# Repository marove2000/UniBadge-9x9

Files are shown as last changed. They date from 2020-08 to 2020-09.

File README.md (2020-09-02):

# UniBadge 9x9
A simple badge PCP with 9x9 LEDs. Create symbols, figures, pixel art by just soldering LEDs to the spots you want. No programming needed.

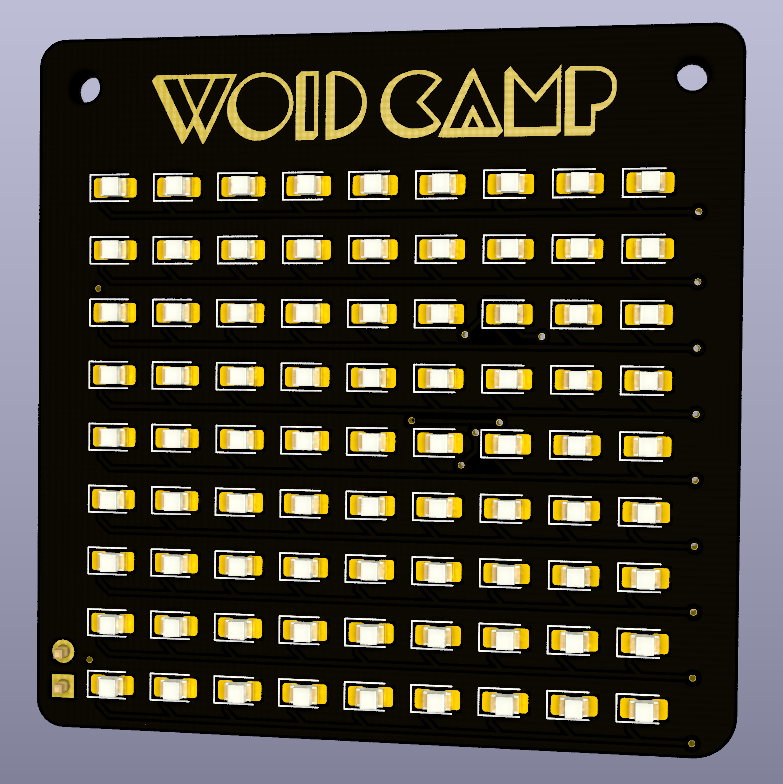
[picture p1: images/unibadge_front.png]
UniBadge 9x9 front
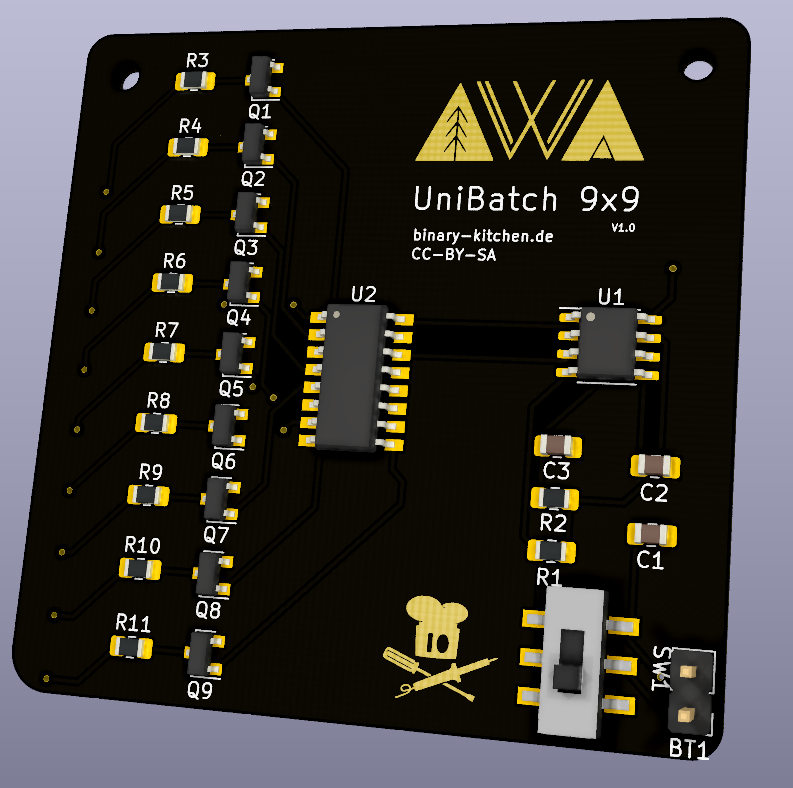
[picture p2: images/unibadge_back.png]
UniBadge 9x9 front
 

## Bill of Material
| Designator | Package | Quantity | Designation |
| --- | --- | --- | --- |
| BT1 | 2-Pin connector | 1 | Battery-Holder (2xAAA) |
| C1, C2 | 100nF | 2 | |
| C3 | 0805 SMD capacitor | 1 | variable (see capaictor table) |
| D1-D81 | 0805 SMD LED | 1-81 | LED red, green, orange, ... |
| Q1-Q9 | Mosfet | 9 | 2N7002 |
| R1, R2 | 0805 SMD resistor  | 2 | 100k |
| R3-R11 | 0805 SMD resistor  | 9 | variable (see resistor table)  |
| SW1 | SMD switch | 1 | |
| U1 | SOIC-8 NE555 | 1 | |
| U2 | SOP-16 CD4017 | 1 | |

### Capacitor-Table for C3
The frequency is determined by the value of C3. Always on: The frequency is so fast, it looks like all (soldered) LEDs are always on.

| Frequency | Capacitor Value (C3) |
| --- | --- |
| slow (~5Hz) | 1µF |
| faster (~50Hz) | 10nF |
| always on (~110Hz) | 4700pF / 4,7nF |

### Resistor-Table for R3-R11
Resistor values depend on the number of soldered LEDs per row (refer to the table below). Note that you can only choose one LED color per row.

| Number of LEDs | Resistor value for red LEDs | Resistor value for green LEDs (bright!) |
| --- | --- | --- |
| 1 | 56 Ohm | 110 Ohm |
| 2 | 27 Ohm | 56 Ohm |
| 3 | 18 Ohm | 36 Ohm |
| 4 | 15 Ohm | 30 Ohm |
| 5 | 11 Ohm | 22 Ohm |
| 6 | 9,1 Ohm | 18 Ohm |
| 7 | 8,2 Ohm | 16 Ohm |
| 8 | 6,8 Ohm | 13 Ohm |
| 9 | 6,2 Ohm | 12 Ohm |

## Manual
TBD

## Some creations
Some $humans did an amazing job. Here are some awesome examples:
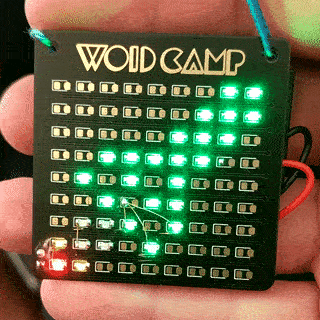
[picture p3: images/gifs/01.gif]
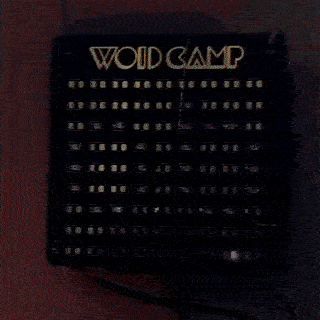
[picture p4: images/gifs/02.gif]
 
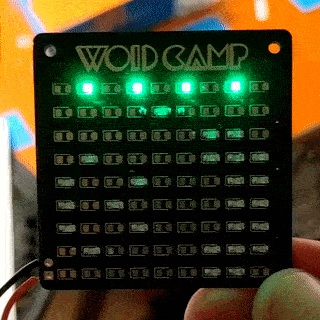
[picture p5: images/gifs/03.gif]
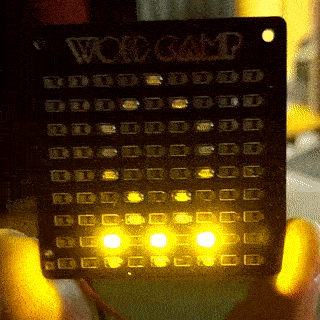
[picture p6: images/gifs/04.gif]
 
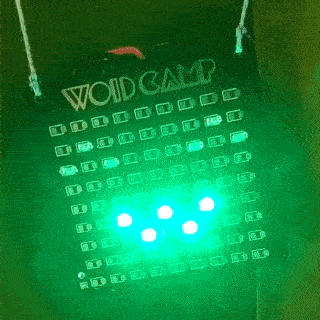
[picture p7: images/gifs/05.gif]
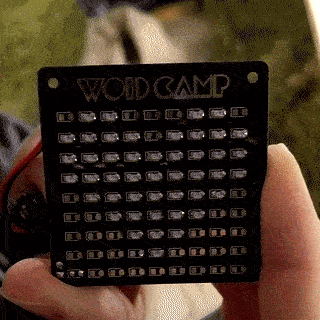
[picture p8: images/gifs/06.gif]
 
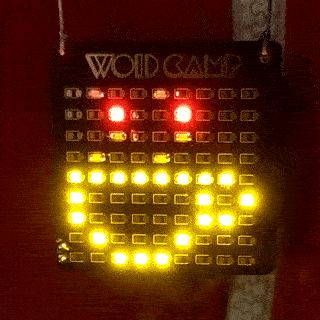
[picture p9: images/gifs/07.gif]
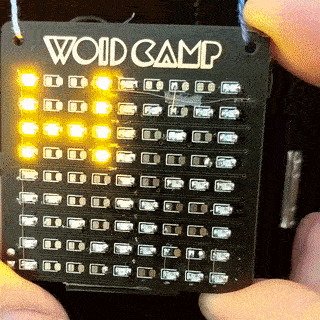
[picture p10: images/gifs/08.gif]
 
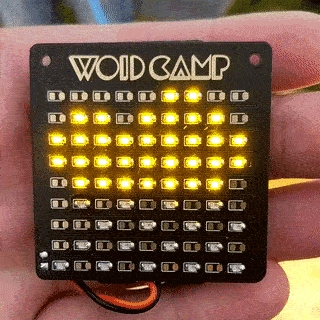
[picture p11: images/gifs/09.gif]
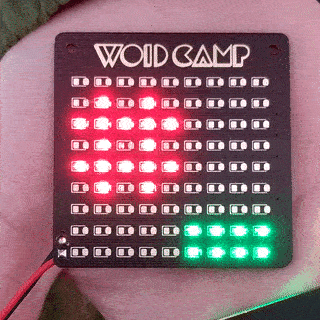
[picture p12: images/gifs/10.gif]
 
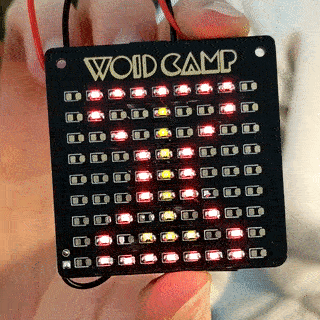
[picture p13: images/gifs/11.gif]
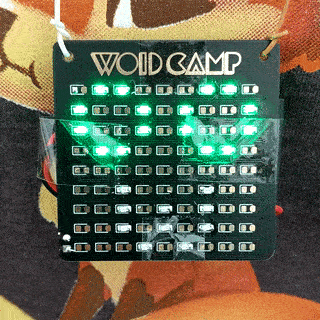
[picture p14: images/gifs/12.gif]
 
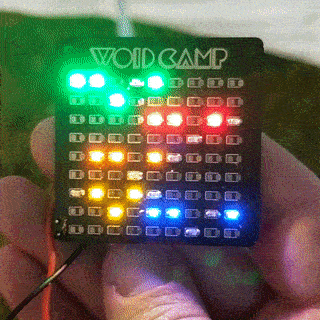
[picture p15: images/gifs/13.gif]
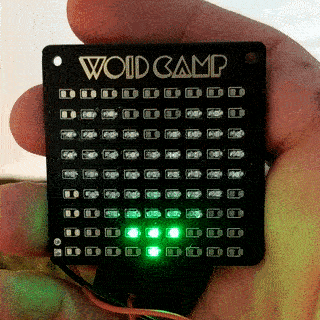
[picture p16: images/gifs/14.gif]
 
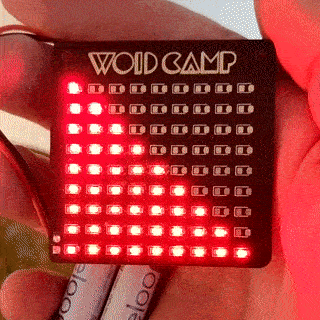
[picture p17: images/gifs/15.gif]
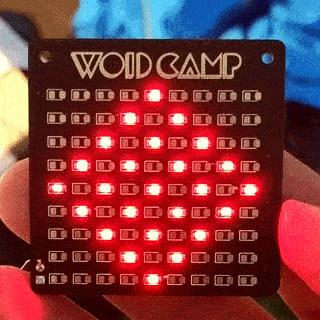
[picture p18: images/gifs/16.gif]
 
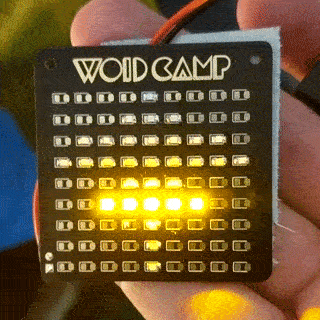
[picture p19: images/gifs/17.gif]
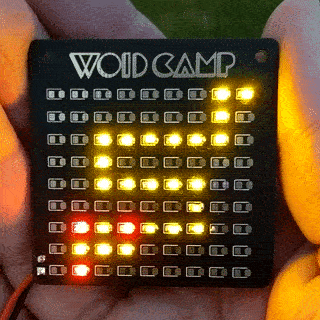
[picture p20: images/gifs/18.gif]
 

## Copyright and Authorship
- PCB layout: [CC-BY-SA 4.0](https://creativecommons.org/licenses/by-sa/4.0/) - [Thomas Schmid and Timo Schindler](https://www.binary-kitchen.de)
- Manual (TeX): [LPPL](https://www.latex-project.org/lppl.txt) - [Marei Peischl](https://peitex.de)
- Manual (pdf): [CC-BY-SA 4.0](https://creativecommons.org/licenses/by-sa/4.0/) - [Binary Kitchen e.V.](https://www.binary-kitchen.de)

## Acknowledgments
A big thank you goes to Thomas Schmid, Clemens Grünewald and Sandra Schweighart for all the help!

The calculation of the frequency done with https://ohmslawcalculator.com/555-astable-calculator

## Misc: Logo to PCB
The Logos to the PCB are created with an Inkscape plugin

- download and install https://github.com/badgeek/svg2shenzhen
- Inkscape: Extensions -> svg2shenzhen -> Prepare Document
- Choose Layer where to place the logo
- Rename: remove "disabled" from layer-name
- Place logo
- Extensions -> svg2shenshen -> Export Kicad (Kicad-module)
- Copy .kicad_mod in .pretty-folder
- Place as part

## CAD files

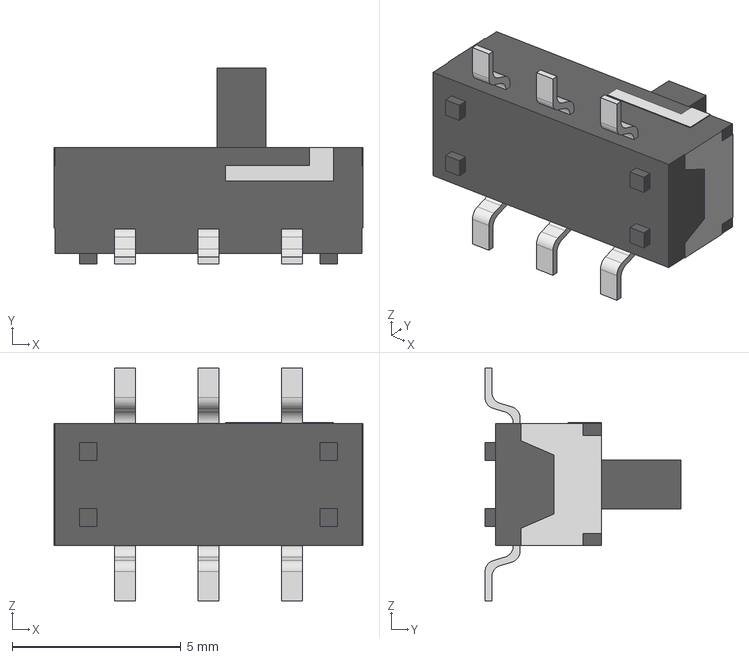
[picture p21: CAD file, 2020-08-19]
kicad/3d-models/Selector Switch - MSS22D18.stp
9.17 x 5.82 x 6.91 mm

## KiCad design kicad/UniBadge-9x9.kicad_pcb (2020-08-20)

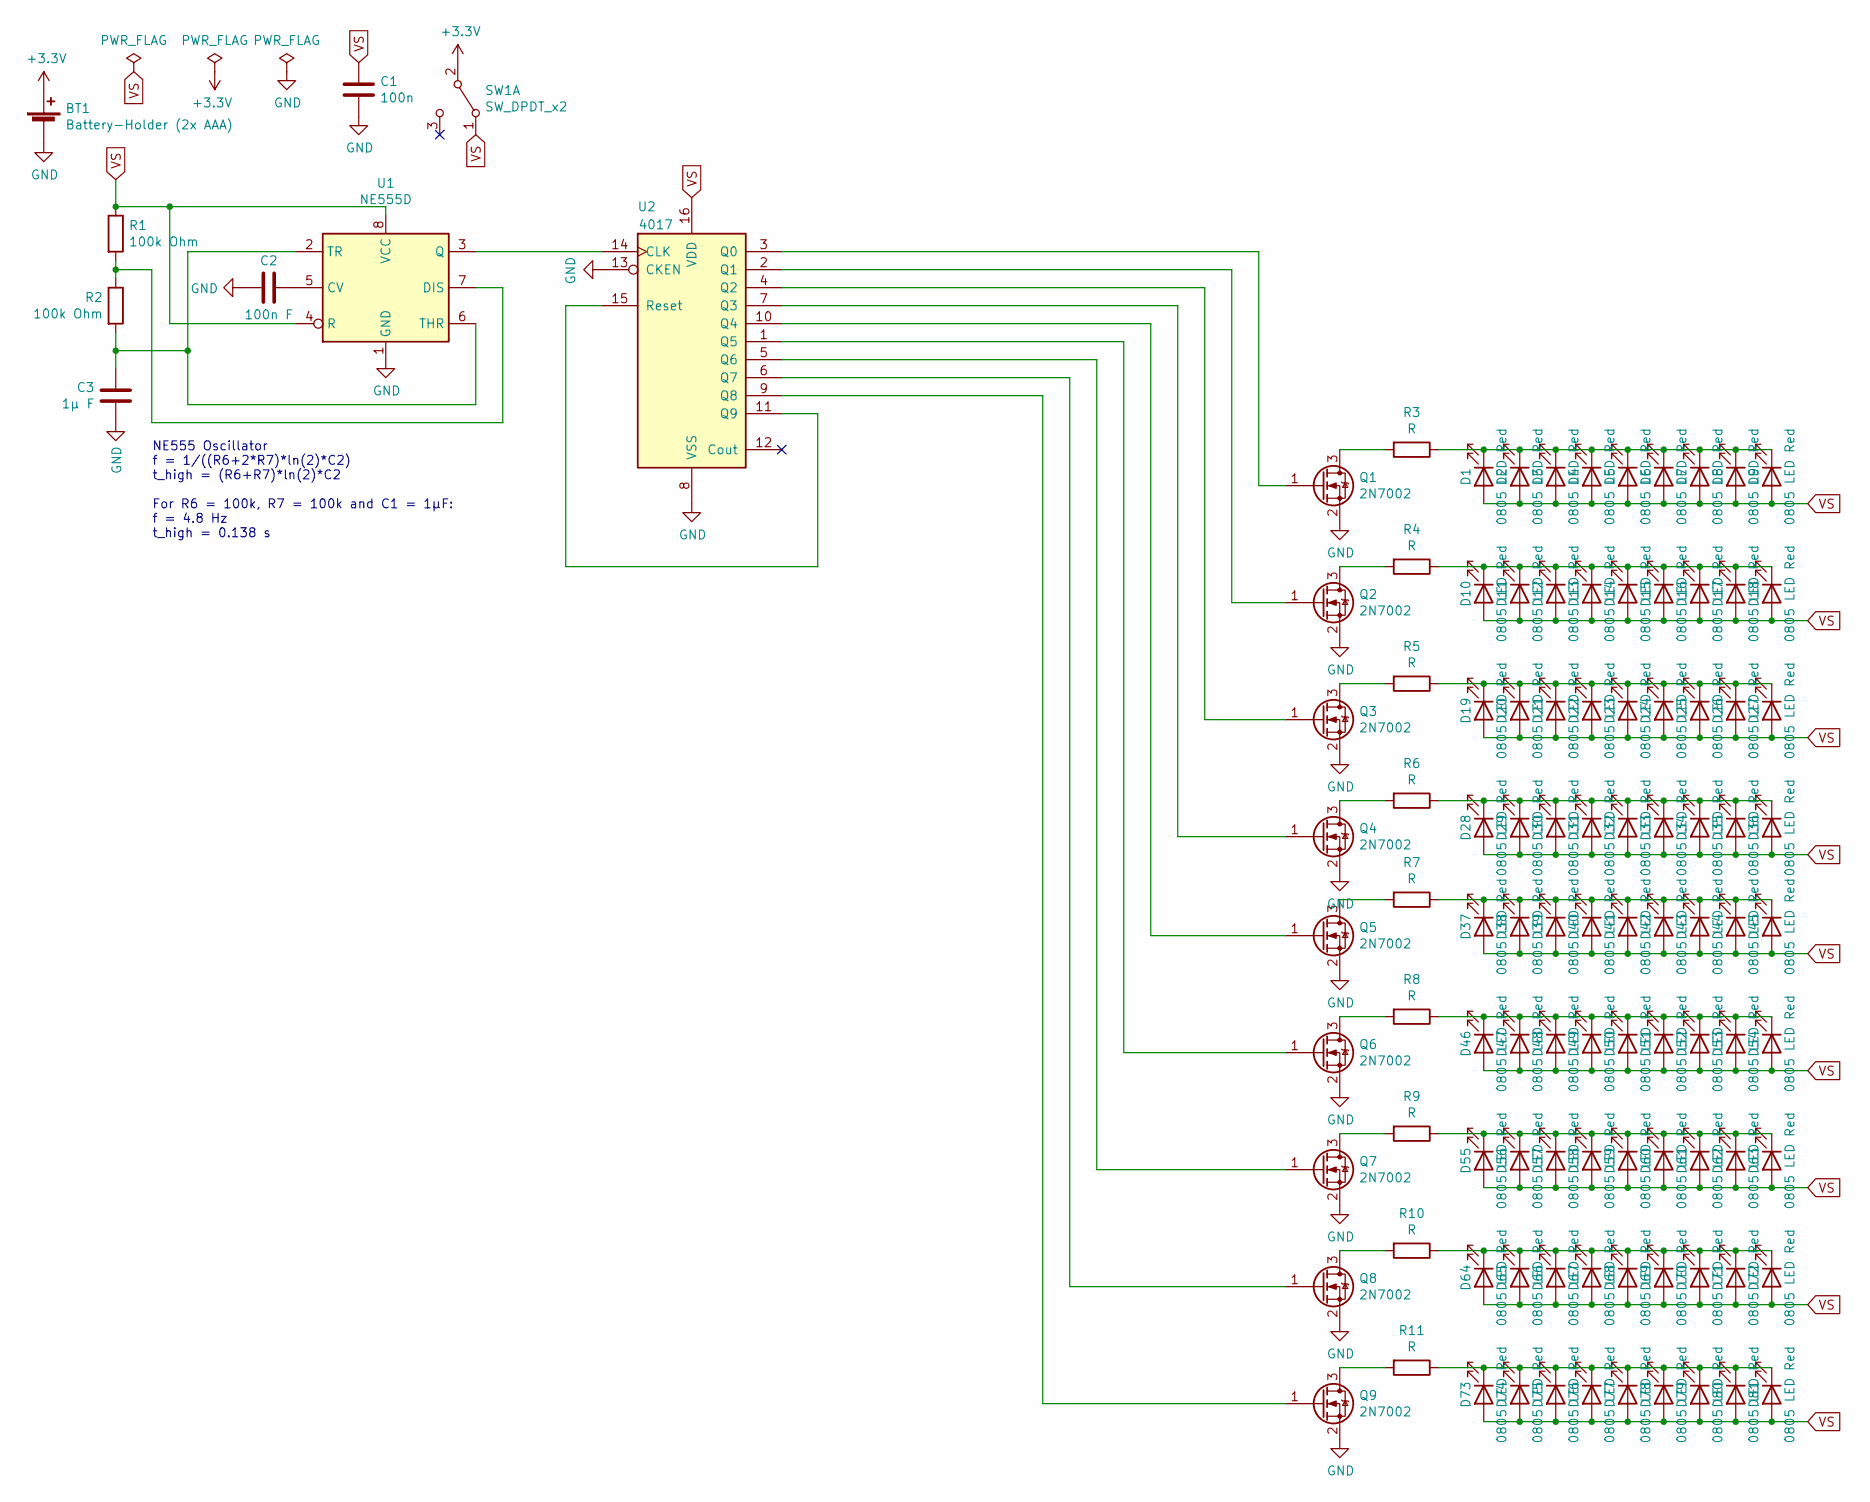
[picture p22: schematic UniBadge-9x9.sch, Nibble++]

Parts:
BT1: Battery-Holder (2x AAA); PinHeader_1x02_P2.54mm_Vertical
C1: 100n; C_0805_2012Metric_Pad1.15x1.40mm_HandSolder
C2: 100n F; C_0805_2012Metric_Pad1.15x1.40mm_HandSolder
C3: 1µ F; C_0805_2012Metric_Pad1.15x1.40mm_HandSolder
D1, D2, D3, D4, D5, D6, D7, D8, D9, D10, D11, D12, D13, D14, D15, D16, D17, D18, D19, D20, D21, D22, D23, D24, D25, D26, D27, D28, D29, D30, D31, D32, D33, D34, D35, D36, D37, D38, D39, D40, D41, D42, D43, D44, D45, D46, D47, D48, D49, D50, D51, D52, D53, D54, D55, D56, D57, D58, D59, D60, D61, D62, D63, D64, D65, D66, D67, D68, D69, D70, D71, D72, D73, D74, D75, D76, D77, D78, D79, D80, D81: 0805 LED Red; LED_0805_2012Metric_Pad1.15x1.40mm_HandSolder
Q1, Q2, Q3, Q4, Q5, Q6, Q7, Q8, Q9: 2N7002; SOT-23
R1, R2: 100k Ohm; R_0805_2012Metric_Pad1.15x1.40mm_HandSolder
R3, R4, R5, R6, R7, R8, R9, R10, R11: R; R_0805_2012Metric_Pad1.15x1.40mm_HandSolder
SW1: SW_DPDT_x2; smd_switch_slide
U1: NE555D; SOIC-8_3.9x4.9mm_P1.27mm
U2: 4017; SOP-16_4.4x10.4mm_P1.27mm_simple_drawing

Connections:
+3V3: BT1.1 (+), SW1.2 (B)
GND: BT1.2 (-), C1.1, C2.2, C3.1, Q1.2 (S), Q2.2 (S), Q3.2 (S), Q4.2 (S), Q5.2 (S), Q6.2 (S), Q7.2 (S), Q8.2 (S), Q9.2 (S), U1.1 (GND), U2.8 (VSS), U2.13 (CKEN)
unnamed: C2.1, U1.5 (CV)
unnamed: C3.2, R2.2, U1.2 (TR), U1.6 (THR)
unnamed: D1.1 (K), D2.1 (K), D3.1 (K), D4.1 (K), D5.1 (K), D6.1 (K), D7.1 (K), D8.1 (K), D9.1 (K), R3.1
unnamed: D10.1 (K), D11.1 (K), D12.1 (K), D13.1 (K), D14.1 (K), D15.1 (K), D16.1 (K), D17.1 (K), D18.1 (K), R4.1
unnamed: D19.1 (K), D20.1 (K), D21.1 (K), D22.1 (K), D23.1 (K), D24.1 (K), D25.1 (K), D26.1 (K), D27.1 (K), R5.1
unnamed: D28.1 (K), D29.1 (K), D30.1 (K), D31.1 (K), D32.1 (K), D33.1 (K), D34.1 (K), D35.1 (K), D36.1 (K), R6.1
unnamed: D37.1 (K), D38.1 (K), D39.1 (K), D40.1 (K), D41.1 (K), D42.1 (K), D43.1 (K), D44.1 (K), D45.1 (K), R7.1
unnamed: D46.1 (K), D47.1 (K), D48.1 (K), D49.1 (K), D50.1 (K), D51.1 (K), D52.1 (K), D53.1 (K), D54.1 (K), R8.1
unnamed: D55.1 (K), D56.1 (K), D57.1 (K), D58.1 (K), D59.1 (K), D60.1 (K), D61.1 (K), D62.1 (K), D63.1 (K), R9.1
unnamed: D64.1 (K), D65.1 (K), D66.1 (K), D67.1 (K), D68.1 (K), D69.1 (K), D70.1 (K), D71.1 (K), D72.1 (K), R10.1
unnamed: D73.1 (K), D74.1 (K), D75.1 (K), D76.1 (K), D77.1 (K), D78.1 (K), D79.1 (K), D80.1 (K), D81.1 (K), R11.1
unnamed: Q1.1 (G), U2.3 (Q0)
unnamed: Q1.3 (D), R3.2
unnamed: Q2.1 (G), U2.2 (Q1)
unnamed: Q2.3 (D), R4.2
unnamed: Q3.1 (G), U2.4 (Q2)
unnamed: Q3.3 (D), R5.2
unnamed: Q4.1 (G), U2.7 (Q3)
unnamed: Q4.3 (D), R6.2
unnamed: Q5.1 (G), U2.10 (Q4)
unnamed: Q5.3 (D), R7.2
unnamed: Q6.1 (G), U2.1 (Q5)
unnamed: Q6.3 (D), R8.2
unnamed: Q7.1 (G), U2.5 (Q6)
unnamed: Q7.3 (D), R9.2
unnamed: Q8.1 (G), U2.6 (Q7)
unnamed: Q8.3 (D), R10.2
unnamed: Q9.1 (G), U2.9 (Q8)
unnamed: Q9.3 (D), R11.2
unnamed: R1.2, R2.1, U1.7 (DIS)
unnamed: U1.3 (Q), U2.14 (CLK)
unnamed: U2.11 (Q9), U2.15 (Reset)
VS: C1.2, D1.2 (A), D2.2 (A), D3.2 (A), D4.2 (A), D5.2 (A), D6.2 (A), D7.2 (A), D8.2 (A), D9.2 (A), D10.2 (A), D11.2 (A), D12.2 (A), D13.2 (A), D14.2 (A), D15.2 (A), D16.2 (A), D17.2 (A), D18.2 (A), D19.2 (A), D20.2 (A), D21.2 (A), D22.2 (A), D23.2 (A), D24.2 (A), D25.2 (A), D26.2 (A), D27.2 (A), D28.2 (A), D29.2 (A), D30.2 (A), D31.2 (A), D32.2 (A), D33.2 (A), D34.2 (A), D35.2 (A), D36.2 (A), D37.2 (A), D38.2 (A), D39.2 (A), D40.2 (A), D41.2 (A), D42.2 (A), D43.2 (A), D44.2 (A), D45.2 (A), D46.2 (A), D47.2 (A), D48.2 (A), D49.2 (A), D50.2 (A), D51.2 (A), D52.2 (A), D53.2 (A), D54.2 (A), D55.2 (A), D56.2 (A), D57.2 (A), D58.2 (A), D59.2 (A), D60.2 (A), D61.2 (A), D62.2 (A), D63.2 (A), D64.2 (A), D65.2 (A), D66.2 (A), D67.2 (A), D68.2 (A), D69.2 (A), D70.2 (A), D71.2 (A), D72.2 (A), D73.2 (A), D74.2 (A), D75.2 (A), D76.2 (A), D77.2 (A), D78.2 (A), D79.2 (A), D80.2 (A), D81.2 (A), R1.1, SW1.1 (A), U1.4 (R), U1.8 (VCC), U2.16 (VDD)

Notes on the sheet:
NE555 Oscillator f = 1/((R6+2*R7)*ln(2)*C2) t_high = (R6+R7)*ln(2)*C2 For R6 = 100k, R7 = 100k and C1 = 1µF: f = 4.8 Hz t_high = 0.138 s

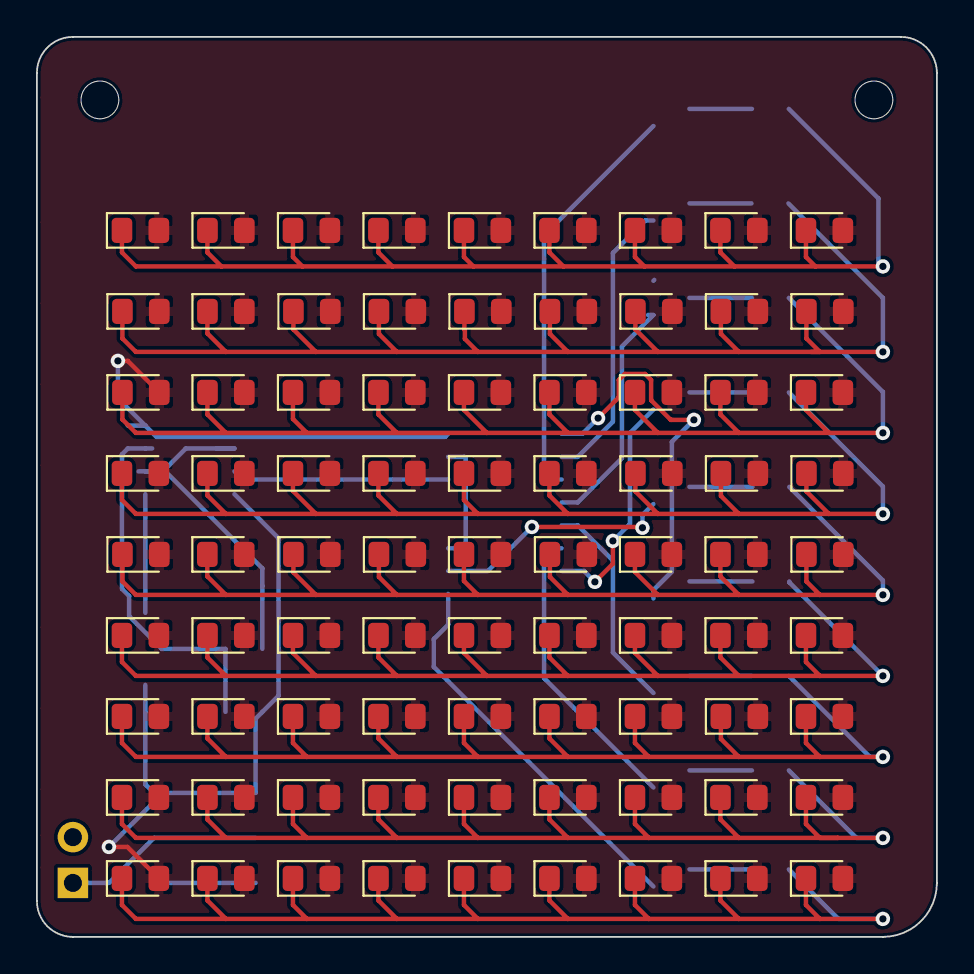
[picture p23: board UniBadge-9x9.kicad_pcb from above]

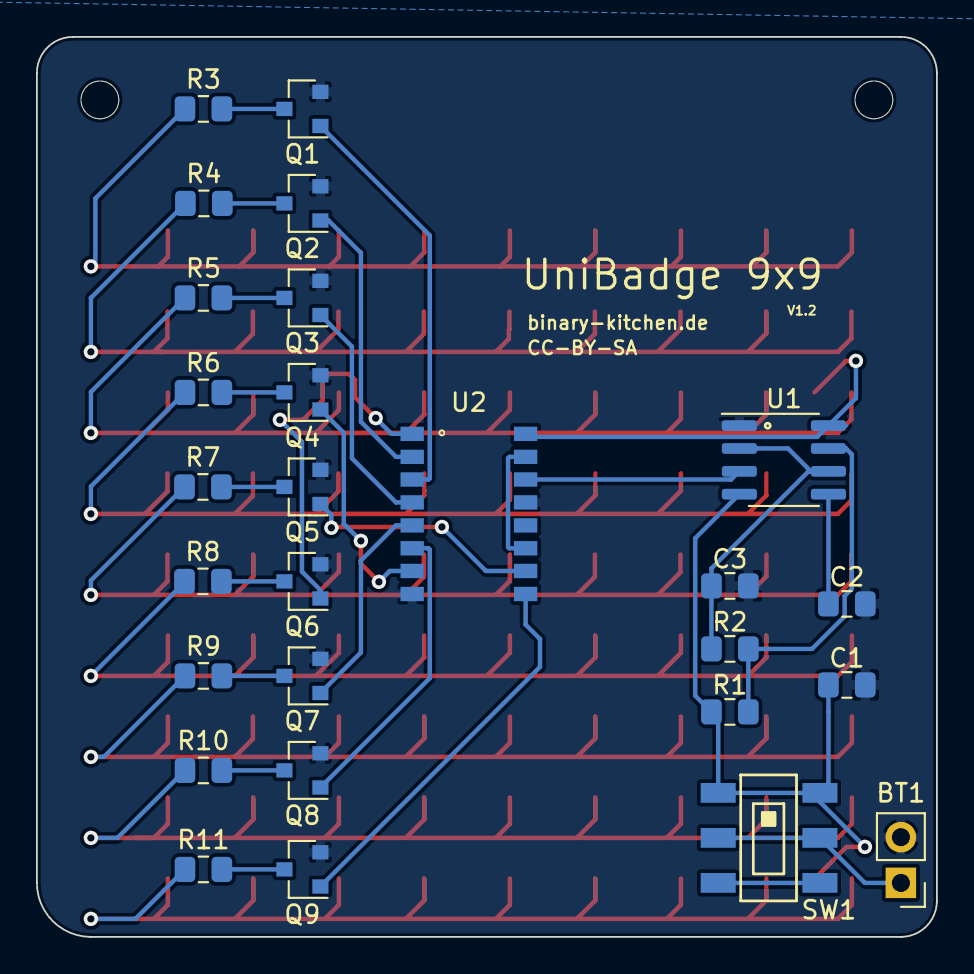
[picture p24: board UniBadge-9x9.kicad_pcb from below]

Board: 2 copper layers, 50.0 x 50.0 mm, 110 parts (27 on the bottom side), 35 nets.

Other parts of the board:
Ref**: Val**; vvoidcamp-logo
Ref**#2: Val**; vvoidcamp-schriftzug

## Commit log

2020-07-25 inital commit
    [unibatch.kicad_pcb, unibatch.sch]
2020-08-05 changed layout to simpler 9x9 leds
    [unibatch-9x9.sch, unibatch.kicad_pcb, unibatch.sch]
2020-08-19 added some misc files
    [LED-Matrix.ods]
2020-08-19 finished layout
    [CR2032 holder.step, Selector Switch - MSS22D18.stp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]
2020-08-19 deleted gerber.zip
2020-08-19 added new gerber files
    [unibatch-9x9-B_Cu.gbr, unibatch-9x9-B_Mask.gbr, unibatch-9x9-B_Paste.gbr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]
2020-08-19 fixed some minor bugs
    [unibatch-9x9.kicad_pcb, unibatch-9x9.sch]
2020-08-19 generated new gerberfile
    [UniBadge-9x9-B_Cu.gbr, UniBadge-9x9-B_Mask.gbr, UniBadge-9x9-B_Paste.gbr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]
2020-08-19 renamed unibatch to unibadge ... germans...
    [CR2032 holder.step, UniBadge-9x9.kicad_pcb, UniBadge-9x9.sch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]
2020-08-19 added some more info
    [LED-Matrix.ods]
2020-08-19 README: fix typo "pxiel" -> pixel
    This rectifies the misspelled "pxiel". Simply replace it with the
    correctly spelled "pixel" ([pˈɪksə͡l], IPA phonetic alphabet).
    As a drive-by catch, remove the trailing whitespace of the affected
    line.
    No functional change.
2020-08-19 README: There is no thing like LED-Color
    use LED color instead.
2020-08-19 README: There is no thing like PCB-layout
    Must be a new invention that I missed.
2020-08-20 fixed clock-enable at cd4017
    [UniBadge-9x9.kicad_pcb, UniBadge-9x9.sch]
2020-08-20 generated new gerber-files
    [UniBadge-9x9-B_Cu.gbr, UniBadge-9x9-B_Mask.gbr, UniBadge-9x9-B_Paste.gbr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]
2020-08-25 Updated resistor values for LEDs
